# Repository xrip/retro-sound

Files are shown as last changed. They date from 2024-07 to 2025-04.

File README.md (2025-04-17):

# RP2040 Retro Sound

## What is?
RP2040 Retro Sound is a project that enables the Raspberry Pi Pico (RP2040) to serve as a COM port passthrough for various FM retro sound chips like the SAA1099, SN76489, YM3812, and YMF262. 

[Interactive BOM (bill of materials)](https://xrip.github.io/retro-sound/hardware/bom/ibom.html)

Assembled PCB:

assembled pcb

Gerbers available via releases, or you can use whole KiCad project from ``hardware`` folder

With this setup, you can bring the authentic sound of classic gaming and computing systems to life using original sound chips. Enjoy the nostalgia of retro audio in a modern, convenient package!

## Purpose
The goal of this project is to allow enthusiasts to listen to retro sound with real sound chips without needing any other retro hardware.

## How to use
To use this project, you will need a modified version of <a href="https://github.com/xrip/retro-sound-dosbox-x/tree/master">DosBox-X</a> or a Sega Master System/Sega Genesis emulator that can passthrough sound data directly to the chips via a COM port. COM7 hardcoded right now.

The operation protocol is straightforward and consists of two-byte transfers. The first byte is the command byte:

```
/*
 * 76543210 - command byte
 * ||||||||
 * |||||||+-- chip 0 / chip 1
 * ||||||+--- address or data
 * ||||++---- reserved
 * ++++------ 0x0...0xE chip id:
 *
 *            0x0 - SN76489 (Tandy 3 voice)
 *            0x1 - YM2413 (OPLL)
 *            0x2 - YM3812 (OPL2)
 *            0x3 - SAA1099 (Creative Music System / GameBlaster)
 *            0x4 - YMF262 (OPL3)
 *            0x5 - YM2612, YM2203, YM2608, YM2610, YMF288 (OPN2 and OPN-compatible series)
 *            ...
 *            0xf - all chips reset/initialization
 */
```

The second byte is the data byte, which is routed directly to the chip.

## Requirements
1. PCB (gerbers available via releases, or you can use whole KiCad project from ``hardware`` dir)
2. RP2040 mini: The microcontroller that powers the project.
4. Retro Sound Chips: Choose from SN76489, SAA1099, YM2413, YM3812, YMF262, or any OPN2 compatible chip. The YMF262 is recommended for its versatility. 
5. Capacitors and Resistors: A few passive components for stable operation.
6. Basic Soldering Skills: Minimal soldering is required to assemble the hardware.

## Credits
PCB designs and all hardware stuff are by Sa Gin

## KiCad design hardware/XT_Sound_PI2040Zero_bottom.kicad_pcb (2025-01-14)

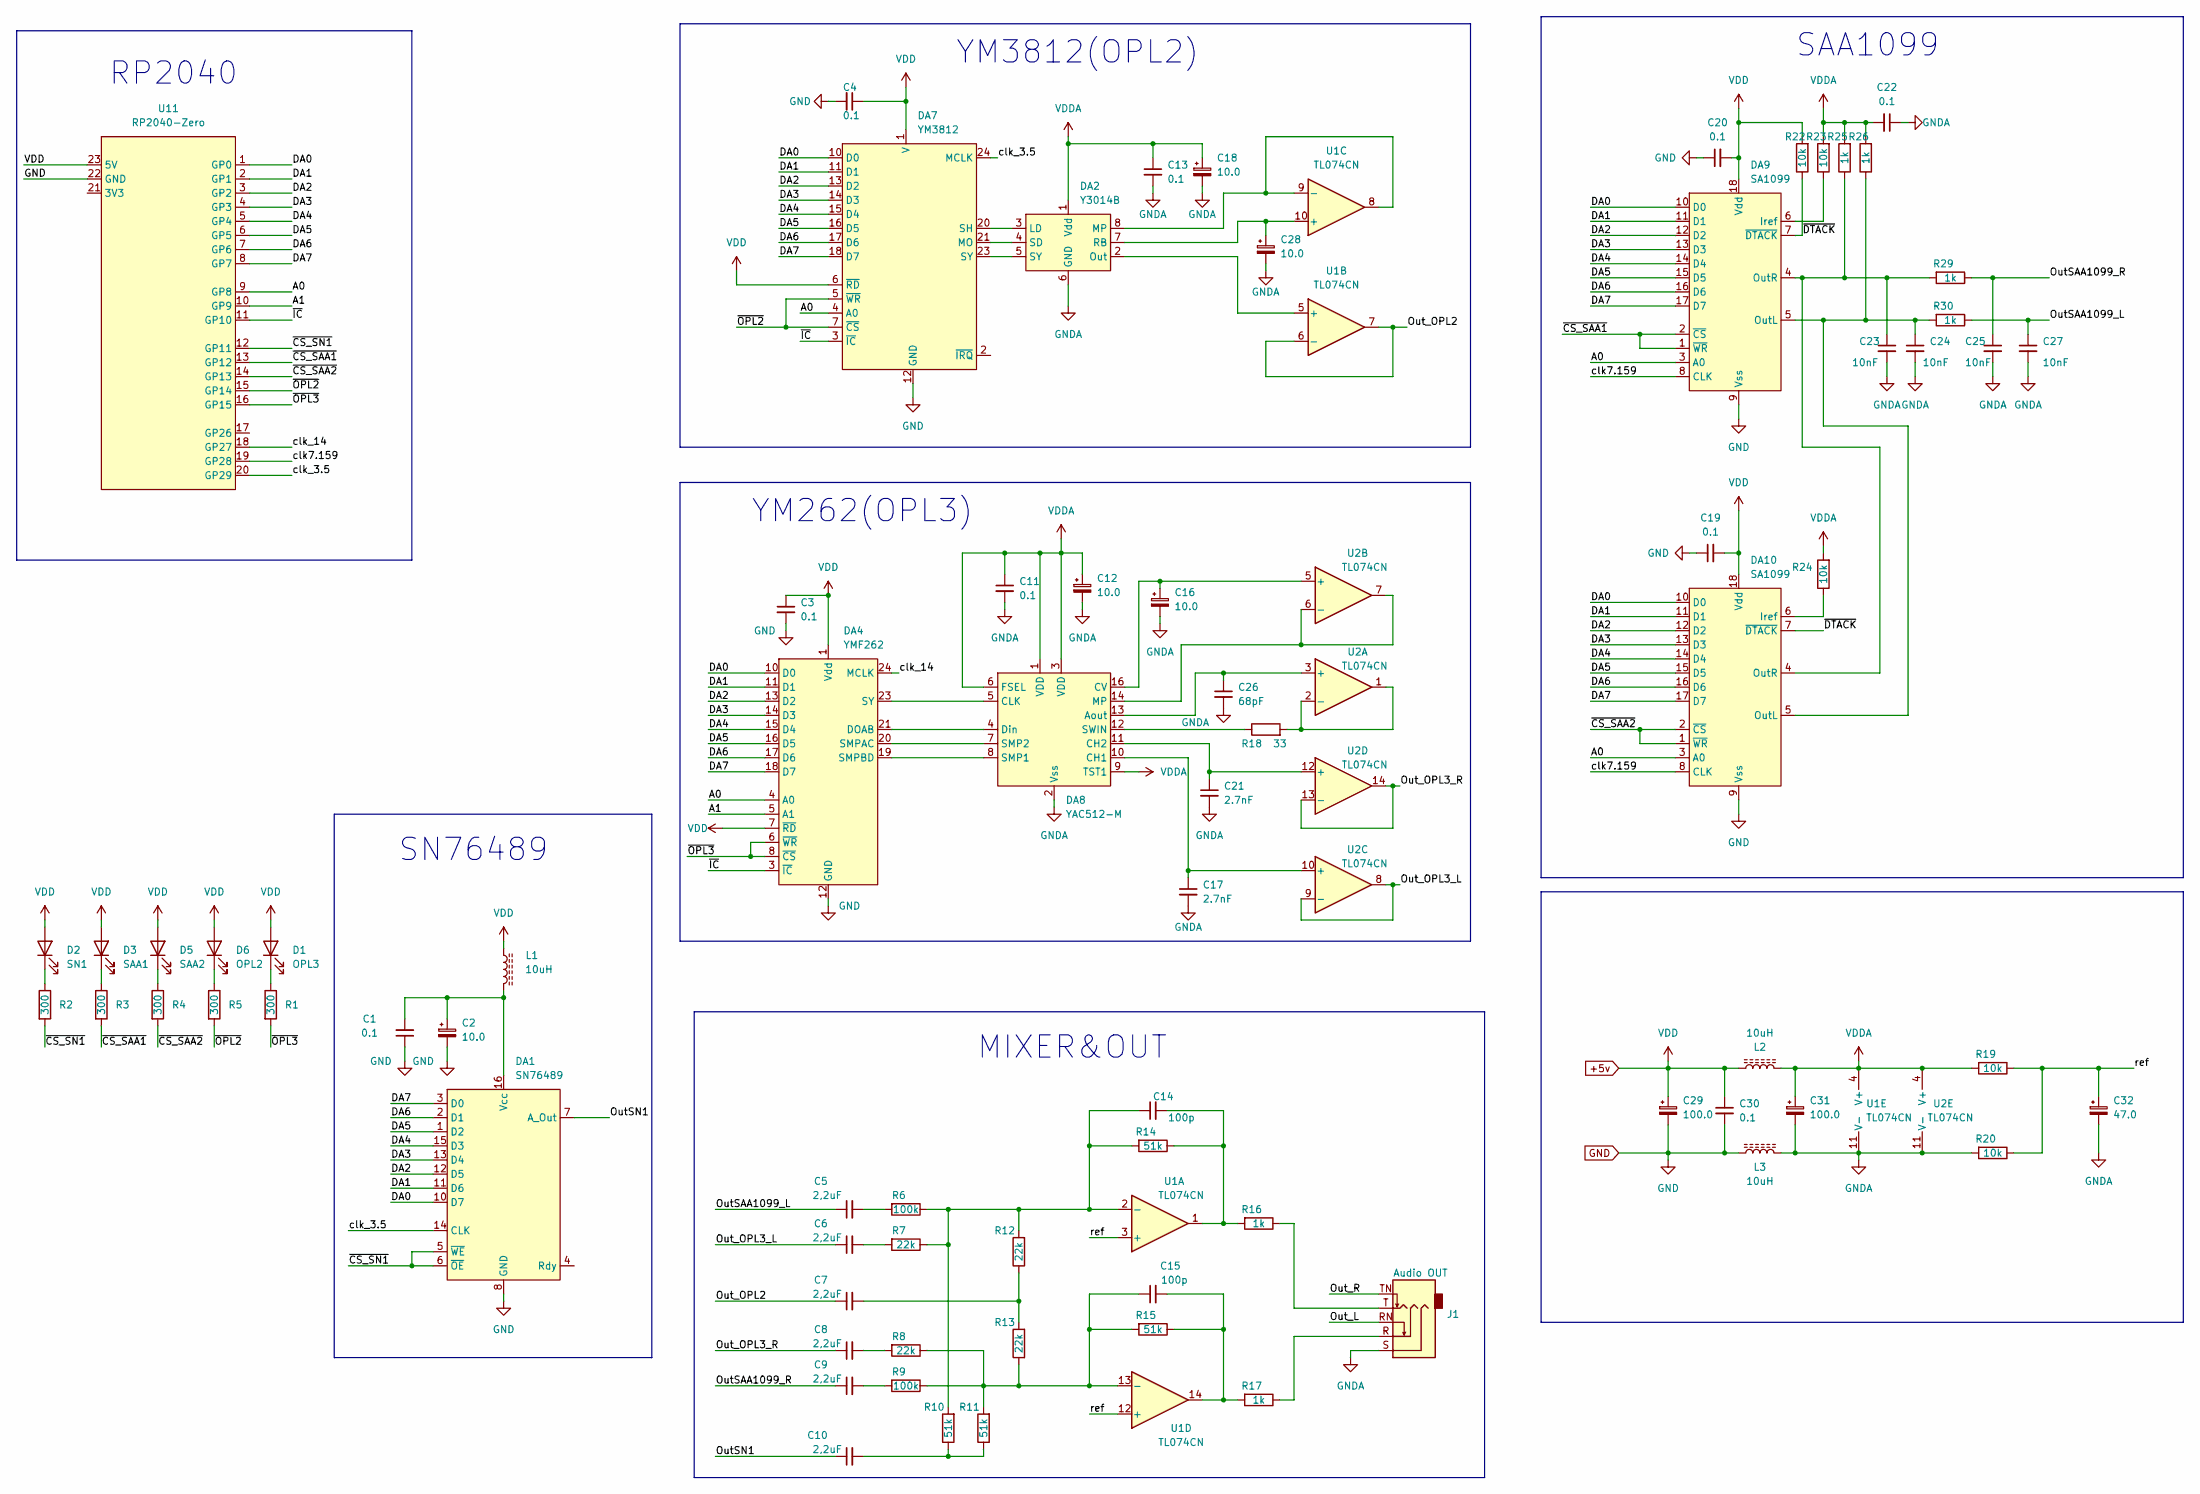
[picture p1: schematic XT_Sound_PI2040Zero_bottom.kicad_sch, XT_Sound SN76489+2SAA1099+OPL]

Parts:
C1, C3, C4, C11, C13, C19, C20, C22, C30: 0.1; C_0805_2012Metric_Pad1.18x1.45mm_HandSolder
C2, C12, C16, C18, C28: 10.0; CP_Elec_4x5.4
C5, C6, C7, C8, C9, C10: 2,2uF; C_0805_2012Metric_Pad1.18x1.45mm_HandSolder
C14, C15: 100p; C_0805_2012Metric_Pad1.18x1.45mm_HandSolder
C17, C21: 2.7nF; C_0805_2012Metric_Pad1.18x1.45mm_HandSolder
C23, C24, C25, C27: 10nF; C_0805_2012Metric_Pad1.18x1.45mm_HandSolder
C26: 68pF; C_0805_2012Metric_Pad1.18x1.45mm_HandSolder
C29, C31: 100.0; CP_Elec_5x5.4
C32: 47.0; CP_Elec_5x5.4
D1: OPL3; LED_Rectangular_W5.0mm_H2.0mm
D2: SN1; LED_Rectangular_W5.0mm_H2.0mm
D3: SAA1; LED_Rectangular_W5.0mm_H2.0mm
D5: SAA2; LED_Rectangular_W5.0mm_H2.0mm
D6: OPL2; LED_Rectangular_W5.0mm_H2.0mm
DA1: SN76489; DIP-16_W7.62mm
DA2: Y3014B; DIP-8_W7.62mm_LongPads
DA4: YMF262; SOP-24_7.5x15.4mm_P1.27mm
DA7: YM3812; DIP-24_W15.24mm
DA8: YAC512-M; SOIC-16_4.55x10.3mm_P1.27mm
DA9, DA10: SA1099; DIP-18_W7.62mm
J1: Audio OUT; Jack_3.5mm_CUI_SJ1-3525N_Horizontal
L1, L2, L3: 10uH; L_0805_2012Metric_Pad1.15x1.40mm_HandSolder
R1, R2, R3, R4, R5: 300; R_0805_2012Metric_Pad1.20x1.40mm_HandSolder
R6, R9: 100k; R_0805_2012Metric_Pad1.20x1.40mm_HandSolder
R7, R8, R12, R13: 22k; R_0805_2012Metric_Pad1.20x1.40mm_HandSolder
R10, R11, R14, R15: 51k; R_0805_2012Metric_Pad1.20x1.40mm_HandSolder
R16, R17, R25, R26, R29, R30: 1k; R_0805_2012Metric_Pad1.20x1.40mm_HandSolder
R18: 33; R_0805_2012Metric_Pad1.20x1.40mm_HandSolder
R19, R20, R22, R23, R24: 10k; R_0805_2012Metric_Pad1.20x1.40mm_HandSolder
U1, U2: TL074CN; DIP-14_W7.62mm_Socket
U11: RP2040-Zero

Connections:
+5v: C3.1, C4.1, C19.2, C20.2, C29.1, C30.1, D1.2 (A), D2.2 (A), D3.2 (A), D5.2 (A), D6.2 (A), DA4.1 (Vdd), DA4.7 (~RD), DA7.1 (V), DA7.6 (~RD), DA9.18 (Vdd), DA10.18 (Vdd), L1.1, L2.1, R22.2, U11.23 (5V)
/A0: DA4.4 (A0), DA7.4 (A0), DA9.3 (A0), DA10.3 (A0), U11.9 (GP8)
/A1: DA4.5 (A1), U11.10 (GP9)
/DA0: DA1.10 (D7), DA4.10 (D0), DA7.10 (D0), DA9.10 (D0), DA10.10 (D0), U11.1 (GP0)
/DA1: DA1.11 (D6), DA4.11 (D1), DA7.11 (D1), DA9.11 (D1), DA10.11 (D1), U11.2 (GP1)
/DA2: DA1.12 (D5), DA4.13 (D2), DA7.13 (D2), DA9.12 (D2), DA10.12 (D2), U11.3 (GP2)
/DA3: DA1.13 (D4), DA4.14 (D3), DA7.14 (D3), DA9.13 (D3), DA10.13 (D3), U11.4 (GP3)
/DA4: DA1.15 (D3), DA4.15 (D4), DA7.15 (D4), DA9.14 (D4), DA10.14 (D4), U11.5 (GP4)
/DA5: DA1.1 (D2), DA4.16 (D5), DA7.16 (D5), DA9.15 (D5), DA10.15 (D5), U11.6 (GP5)
/DA6: DA1.2 (D1), DA4.17 (D6), DA7.17 (D6), DA9.16 (D6), DA10.16 (D6), U11.7 (GP6)
/DA7: DA1.3 (D0), DA4.18 (D7), DA7.18 (D7), DA9.17 (D7), DA10.17 (D7), U11.8 (GP7)
/OutSAA1099_L: C5.1, C27.1, R30.1
/OutSAA1099_R: C9.1, C25.1, R29.1
/OutSN1: C10.1, DA1.7 (A_Out)
/Out_L: J1.RN
/Out_OPL2: C7.1, U1.6 (-), U1.7
/Out_OPL3_L: C6.1, U2.8, U2.9 (-)
/Out_OPL3_R: C8.1, U2.13 (-), U2.14
/Out_R: J1.TN
/clk7.159: DA9.8 (CLK), DA10.8 (CLK), U11.19 (GP28)
/clk_3.5: DA1.14 (CLK), DA7.24 (MCLK), U11.20 (GP29)
/clk_14: DA4.24 (MCLK), U11.18 (GP27)
/ref: C32.1, R19.1, R20.1, U1.3 (+), U1.12 (+)
/~CS_SAA1: DA9.1 (~WR), DA9.2 (~CS), R3.2, U11.13 (GP12)
/~CS_SAA2: DA10.1 (~WR), DA10.2 (~CS), R4.2, U11.14 (GP13)
/~CS_SN1: DA1.5 (~WE), DA1.6 (~OE), R2.2, U11.12 (GP11)
/~DTACK: DA9.7 (~DTACK), DA10.7 (~DTACK), R22.1
/~IC: DA4.3 (~IC), DA7.3 (~IC), U11.11 (GP10)
/~OPL2: DA7.5 (~WR), DA7.7 (~CS), R5.2, U11.15 (GP14)
/~OPL3: DA4.6 (~WR), DA4.8 (~CS), R1.2, U11.16 (GP15)
GND: C1.1, C2.2, C3.2, C4.2, C19.1, C20.1, C29.2, C30.2, DA1.8 (GND), DA4.12 (GND), DA7.12 (GND), DA9.9 (Vss), DA10.9 (Vss), L3.1, U11.22 (GND)
GNDA: C11.2, C12.2, C13.2, C16.2, C17.2, C18.2, C21.2, C22.1, C23.2, C24.2, C25.2, C26.2, C27.2, C28.2, C31.2, C32.2, DA2.6 (GND), DA8.2 (Vss), J1.S, L3.2, R20.2, U1.11 (V-), U2.11 (V-)
unnamed: C1.2, C2.1, DA1.16 (Vcc), L1.2
unnamed: C5.2, R6.2
unnamed: C6.2, R7.2
unnamed: C7.2, R12.1, R13.2
unnamed: C8.2, R8.2
unnamed: C9.2, R9.2
unnamed: C10.2, R10.1, R11.1
unnamed: C14.1, R6.1, R7.1, R10.2, R12.2, R14.2, U1.2 (-)
unnamed: C14.2, R14.1, R16.2, U1.1
unnamed: C15.1, R8.1, R9.1, R11.2, R13.1, R15.2, U1.13 (-)
unnamed: C15.2, R15.1, R17.2, U1.14
unnamed: C16.1, DA8.16 (CV), U2.5 (+)
unnamed: C17.1, DA8.10 (CH1), U2.10 (+)
unnamed: C21.1, DA8.11 (CH2), U2.12 (+)
unnamed: C23.1, DA9.4 (OutR), DA10.4 (OutR), R25.1, R29.2
unnamed: C24.1, DA9.5 (OutL), DA10.5 (OutL), R26.1, R30.2
unnamed: C26.1, DA8.13 (Aout), U2.3 (+)
unnamed: C28.1, DA2.7 (RB), U1.10 (+)
unnamed: D1.1 (K), R1.1
unnamed: D2.1 (K), R2.1
unnamed: D3.1 (K), R3.1
unnamed: D5.1 (K), R4.1
unnamed: D6.1 (K), R5.1
unnamed: DA2.2 (Out), U1.5 (+)
unnamed: DA2.3 (LD), DA7.20 (SH)
unnamed: DA2.4 (SD), DA7.21 (MO)
unnamed: DA2.5 (SY), DA7.23 (SY)
unnamed: DA2.8 (MP), U1.8, U1.9 (-)
unnamed: DA4.19 (SMPBD), DA8.8 (SMP1)
unnamed: DA4.20 (SMPAC), DA8.7 (SMP2)
unnamed: DA4.21 (DOAB), DA8.4 (Din)
unnamed: DA4.23 (SY), DA8.5 (CLK)
unnamed: DA8.12 (SWIN), R18.1
unnamed: DA8.14 (MP), U2.6 (-), U2.7
unnamed: DA9.6 (Iref), R23.1
unnamed: DA10.6 (Iref), R24.1
unnamed: J1.R, R17.1
unnamed: J1.T, R16.1
unnamed: R18.2, U2.1, U2.2 (-)
VDDA: C11.1, C12.1, C13.1, C18.1, C22.2, C31.1, DA2.1 (Vdd), DA8.1 (VDD), DA8.3 (VDD), DA8.6 (FSEL), DA8.9 (TST1), L2.2, R19.2, R23.2, R24.2, R25.2, R26.2, U1.4 (V+), U2.4 (V+)

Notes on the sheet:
YM262(OPL3)
YM3812(OPL2)
MIXER&OUT
SAA1099
RP2040
SN76489

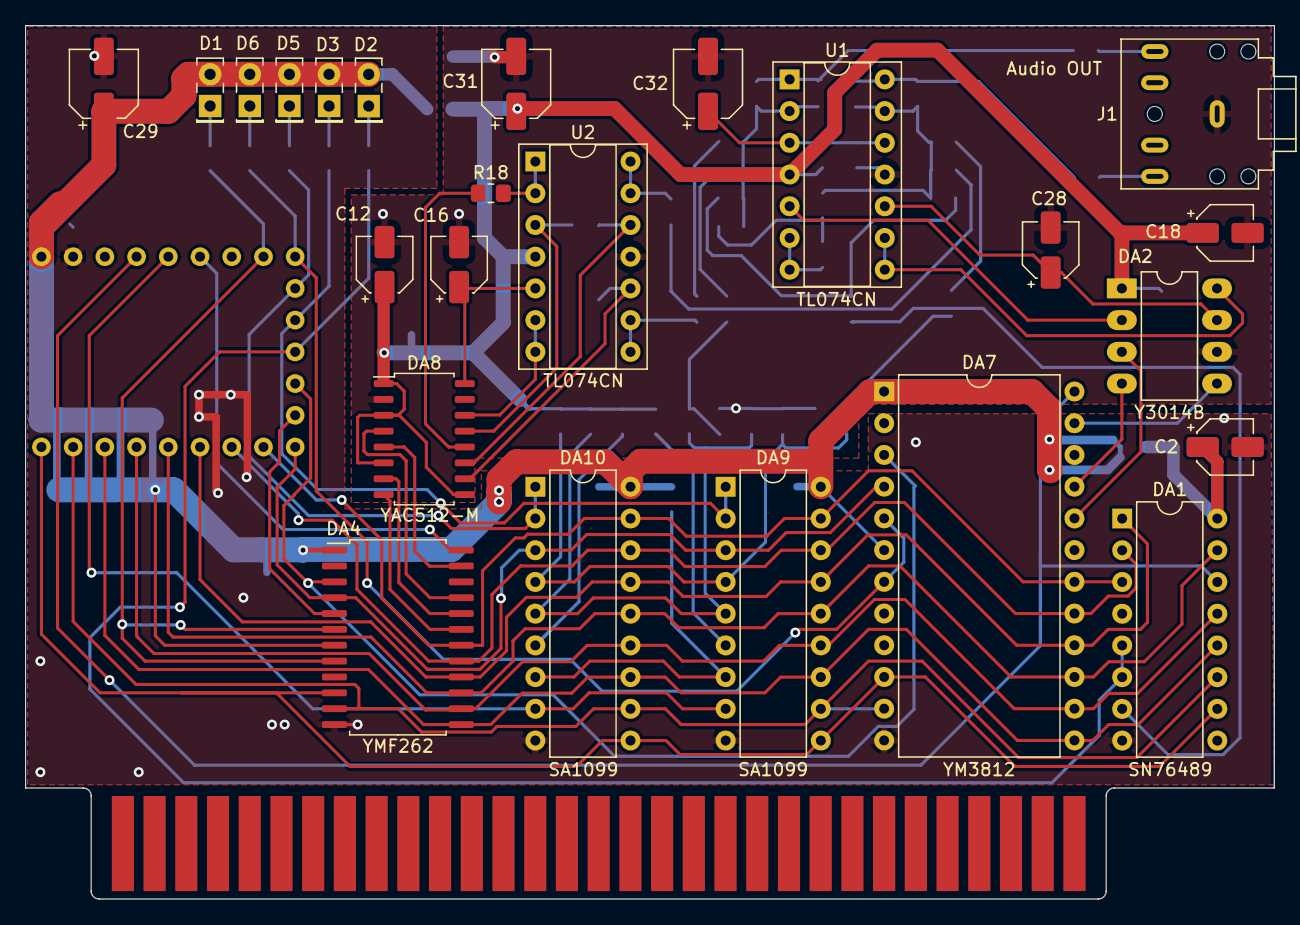
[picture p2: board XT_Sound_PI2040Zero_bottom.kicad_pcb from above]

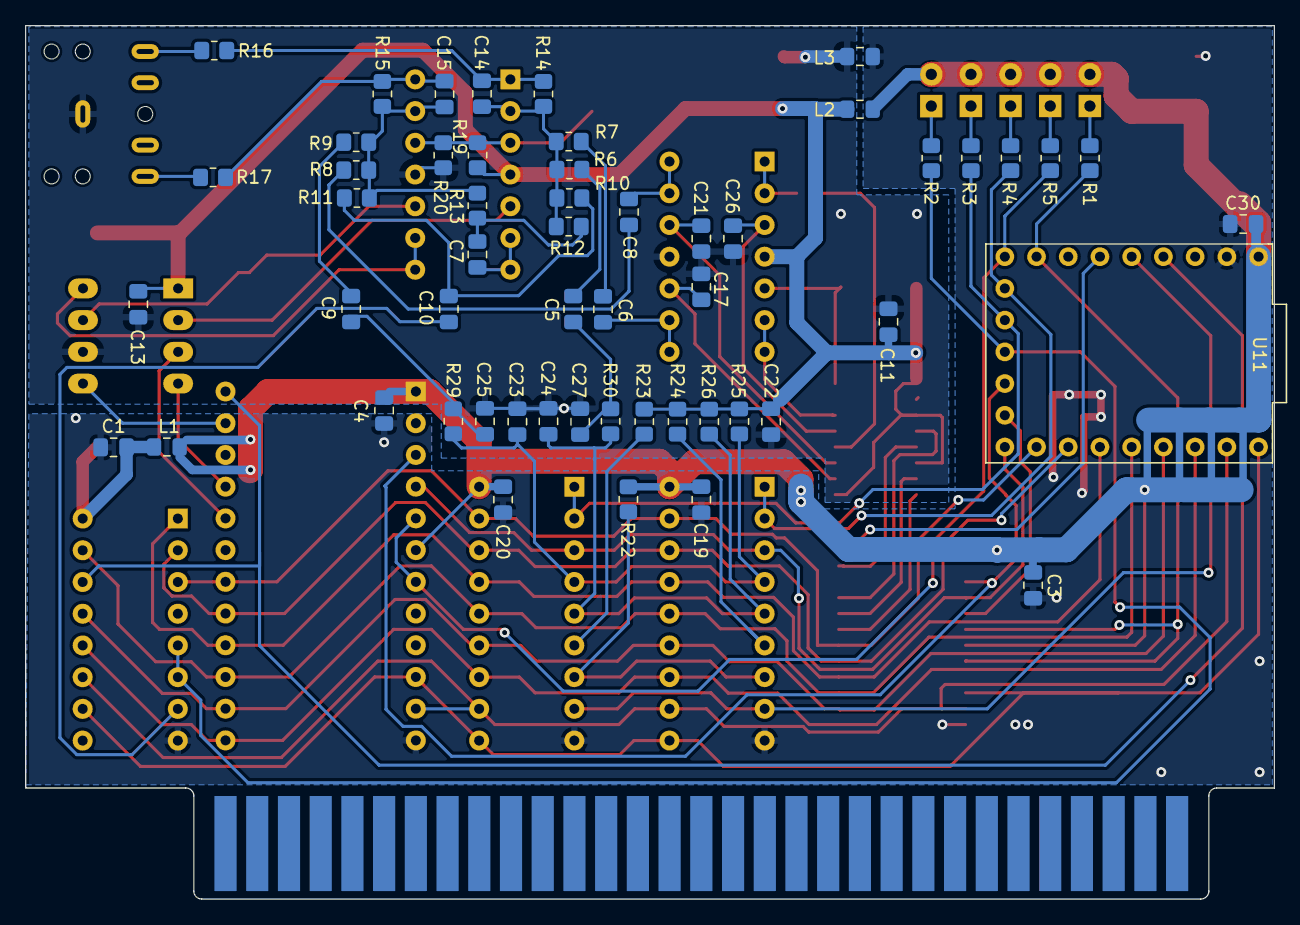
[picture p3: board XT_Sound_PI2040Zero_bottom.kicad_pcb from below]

Board: 2 copper layers, 100.0 x 69.9 mm, 78 parts (54 on the bottom side), 70 nets.

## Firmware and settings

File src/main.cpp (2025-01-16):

#include <cstdio>
#include <pico/stdio_usb.h>
#include <pico/runtime.h>
#include <pico/multicore.h>
#include <hardware/structs/vreg_and_chip_reset.h>
#include <hardware/structs/clocks.h>
#include <hardware/clocks.h>
#include <hardware/gpio.h>

#include "ws2812b.h"
#include "pio_clock_generator.h"

#define TIMER_PERIOD_MS 1

#define OUT_PIN_MASK 0x0000ffff
#define IC (1 << 8)
#define A0 (1 << 9)
#define A1 (1 << 10)

#define SN_1_CS  (1 << 11)
#define SAA_1_CS (1 << 12)
#define SAA_2_CS (1 << 13)
#define OPL2     (1 << 14)
#define OPL3     (1 << 15)


uint16_t control_bits = 0;
#define LOW(x) (control_bits &= ~(x))
#define HIGH(x) (control_bits |= (x))


#if defined(SN76489_REVERSED)
// Если мы перепутаем пины
static const uint8_t  __aligned(4) reversed[] = {
        0x00, 0x80, 0x40, 0xC0, 0x20, 0xA0, 0x60, 0xE0, 0x10, 0x90, 0x50, 0xD0, 0x30, 0xB0, 0x70, 0xF0,
        0x08, 0x88, 0x48, 0xC8, 0x28, 0xA8, 0x68, 0xE8, 0x18, 0x98, 0x58, 0xD8, 0x38, 0xB8, 0x78, 0xF8,
        0x04, 0x84, 0x44, 0xC4, 0x24, 0xA4, 0x64, 0xE4, 0x14, 0x94, 0x54, 0xD4, 0x34, 0xB4, 0x74, 0xF4,
        0x0C, 0x8C, 0x4C, 0xCC, 0x2C, 0xAC, 0x6C, 0xEC, 0x1C, 0x9C, 0x5C, 0xDC, 0x3C, 0xBC, 0x7C, 0xFC,
        0x02, 0x82, 0x42, 0xC2, 0x22, 0xA2, 0x62, 0xE2, 0x12, 0x92, 0x52, 0xD2, 0x32, 0xB2, 0x72, 0xF2,
        0x0A, 0x8A, 0x4A, 0xCA, 0x2A, 0xAA, 0x6A, 0xEA, 0x1A, 0x9A, 0x5A, 0xDA, 0x3A, 0xBA, 0x7A, 0xFA,
        0x06, 0x86, 0x46, 0xC6, 0x26, 0xA6, 0x66, 0xE6, 0x16, 0x96, 0x56, 0xD6, 0x36, 0xB6, 0x76, 0xF6,
        0x0E, 0x8E, 0x4E, 0xCE, 0x2E, 0xAE, 0x6E, 0xEE, 0x1E, 0x9E, 0x5E, 0xDE, 0x3E, 0xBE, 0x7E, 0xFE,
        0x01, 0x81, 0x41, 0xC1, 0x21, 0xA1, 0x61, 0xE1, 0x11, 0x91, 0x51, 0xD1, 0x31, 0xB1, 0x71, 0xF1,
        0x09, 0x89, 0x49, 0xC9, 0x29, 0xA9, 0x69, 0xE9, 0x19, 0x99, 0x59, 0xD9, 0x39, 0xB9, 0x79, 0xF9,
        0x05, 0x85, 0x45, 0xC5, 0x25, 0xA5, 0x65, 0xE5, 0x15, 0x95, 0x55, 0xD5, 0x35, 0xB5, 0x75, 0xF5,
        0x0D, 0x8D, 0x4D, 0xCD, 0x2D, 0xAD, 0x6D, 0xED, 0x1D, 0x9D, 0x5D, 0xDD, 0x3D, 0xBD, 0x7D, 0xFD,
        0x03, 0x83, 0x43, 0xC3, 0x23, 0xA3, 0x63, 0xE3, 0x13, 0x93, 0x53, 0xD3, 0x33, 0xB3, 0x73, 0xF3,
        0x0B, 0x8B, 0x4B, 0xCB, 0x2B, 0xAB, 0x6B, 0xEB, 0x1B, 0x9B, 0x5B, 0xDB, 0x3B, 0xBB, 0x7B, 0xFB,
        0x07, 0x87, 0x47, 0xC7, 0x27, 0xA7, 0x67, 0xE7, 0x17, 0x97, 0x57, 0xD7, 0x37, 0xB7, 0x77, 0xF7,
        0x0F, 0x8F, 0x4F, 0xCF, 0x2F, 0xAF, 0x6F, 0xEF, 0x1F, 0x9F, 0x5F, 0xDF, 0x3F, 0xBF, 0x7F, 0xFF
};
#endif

static inline bool overclock() {
    hw_set_bits(&vreg_and_chip_reset_hw->vreg, VREG_AND_CHIP_RESET_VREG_VSEL_BITS);
    sleep_ms(10);
    return set_sys_clock_khz(396 * KHZ, true);
}

static inline void write_GPIO(const uint16_t data, const uint16_t delay_us) {
    gpio_put_masked(OUT_PIN_MASK, data);
    busy_wait_us(delay_us);
}


static inline uint32_t time_ms() {
    return time_us_32() >> 10; //0-4194190
}


// SN76489
static inline void SN76489_write(uint8_t byte) {
#if defined(SN76489_REVERSED)
    byte = reversed[byte];
#endif
    write_GPIO(byte | LOW(SN_1_CS), 20);
    write_GPIO(byte | HIGH(SN_1_CS), 0);
}

// YM2413
static inline void YM2413_write(const uint8_t addr, const uint8_t byte) {
    const uint16_t a0 = addr ? A0 : 0;
    write_GPIO(byte | a0 | LOW(OPL2), 4);
    write_GPIO(byte | a0 | HIGH(OPL2), a0 ? 30 : 5);
}

// SAA1099
static inline void SAA1099_write(const uint8_t addr, const uint8_t chip, const uint8_t byte) {
    const uint16_t a0 = addr ? A0 : 0;
    const uint16_t cs = chip ? SAA_2_CS : SAA_1_CS;

    write_GPIO(byte | a0 | LOW(cs), 5);
    write_GPIO(byte | a0 | HIGH(cs), 0);
}

// YM3812
static inline void YM3812_write_byte(const uint16_t addr, const uint16_t register_set, const uint8_t byte) {
    const uint16_t a0 = addr ? A0 : 0;
    const uint16_t a1 = register_set ? A1 : 0;

    write_GPIO(byte | a0 | a1 | LOW(OPL2), 5);
    write_GPIO(byte | a0 | a1 | HIGH(OPL2), 30);
}

// YMF262
static inline void YMF262_write_byte(const uint16_t addr, const uint16_t register_set, const uint8_t byte) {
    const uint16_t a0 = addr ? A0 : 0;
    const uint16_t a1 = register_set ? A1 : 0;

    write_GPIO(byte | a0 | a1 | LOW(OPL3), 5);
    write_GPIO(byte | a0 | a1 | HIGH(OPL3), 0);
}

enum chip_type {
    SN76489,
    YM2413,
    YM3812,
    SAA1099,
    YMF262,
    YM2612,
    PCM,
};

/*
 * 76543210 - command byte
 * ||||||||
 * |||||||+-- chip 0 / chip 1
 * ||||||+--- address or data
 * ||||++---- reserved
 * ++++------ 0x0...0xE chip id:
 *
 *            0x0 - SN76489 (Tandy 3 voice)
 *            0x1 - YM2413 (OPLL)
 *            0x2 - YM3812 (OPL2)
 *            0x3 - SAA1099 (Creative Music System / GameBlaster)
 *            0x4 - YMF262 (OPL3)
 *            0x5 - YM2612, YM2203, YM2608, YM2610, YMF288 (OPN2 and OPN-compatible series)
 *            ...
 *            0xf - all chips reset/initialization
 */

#define CHIP(b) (b >> 4)
#define CHIPN(b) (b & 1)
#define TYPE(b) (b & 2)

static inline void reset_chips() {
    control_bits = 0;
    write_GPIO(HIGH(SN_1_CS | OPL2 | SAA_1_CS | SAA_2_CS | OPL3 | IC), 10);
    write_GPIO(LOW(IC), 100);
    write_GPIO(HIGH(IC), 10);

    // Mute SN76489
    SN76489_write(0x9F);
    SN76489_write(0xBF);
    SN76489_write(0xDF);
    SN76489_write(0xFF);

    // Mute SAA1099
    SAA1099_write(1, 0, 0x1C);
    SAA1099_write(0, 0, 0);
    SAA1099_write(1, 1, 0x1C);
    SAA1099_write(0, 1, 0);

    for (int i = 0; i < 6; i++) {
        set_ws2812b_HSV(0, i * 40, 250, 40);
        sleep_ms(60);
    }
}

int __time_critical_func() main() {
    overclock();

    stdio_usb_init();

    gpio_init_mask(OUT_PIN_MASK);
    gpio_set_dir_out_masked(OUT_PIN_MASK);

    ini_chips_clocks();

    init_ws2812b();

    reset_chips();

    uint8_t ws2812b_color = 0;
    uint8_t ws2812b_brightness = 0;
    uint32_t timer_update = 0;

    int is_data_byte = false;
    uint8_t command = 0;

    while (true) {
        const int data = getchar_timeout_us(50);

        if (time_ms() - timer_update > TIMER_PERIOD_MS) {
            timer_update = time_ms();

            set_ws2812b_HSV(0, ws2812b_color, 250, ws2812b_brightness);

            if (ws2812b_brightness)
                ws2812b_brightness--;
        }


        if (PICO_ERROR_TIMEOUT != data) {
            if (is_data_byte) {
                ws2812b_brightness = 60;

                switch (CHIP(command)) {
                    case SN76489: /* TODO: GameGear channel mapping */
                        SN76489_write(data);
                        ws2812b_color = 0;
                        break;

                    case YM2413:
                        YM2413_write(TYPE(command), data);
                        ws2812b_color = 30;
                        break;

                    case YMF262:
                        YMF262_write_byte(TYPE(command), CHIPN(command), data);
                        ws2812b_color = 30;
                        break;

                    case YM3812:
                        YM3812_write_byte(TYPE(command), CHIPN(command), data);
                        ws2812b_color = 60;
                        break;

                    case SAA1099:
                        SAA1099_write(TYPE(command), CHIPN(command), data);
                        ws2812b_color = 120;
                        break;

                    case 0xf:
                        reset_chips();
                        break;
                }
            }

            command = data;
            is_data_byte ^= 1;
        }
    }
}

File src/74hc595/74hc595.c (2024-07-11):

#include "74hc595.h"
#include "hardware/clocks.h"
#include "pico/platform.h"

static const uint16_t program_instructions595[] = {
        //     .wrap_target
        0x80a0, //  0: pull   block           side 0
        0x6001, //  1: out    pins, 1         side 0
        0x1041, //  2: jmp    x--, 1          side 2
        0xe82f, //  3: set    x, 15           side 1
        0x6050, //  4: out    y, 16           side 0
        0x0085, //  5: jmp    y--, 5          side 0
        //     .wrap

};

static const struct pio_program program595 = {
        .instructions = program_instructions595,
        .length = 6,
        .origin = -1,
};

void init_74hc595() {
    uint offset = pio_add_program(PIO_74HC595, &program595);
    pio_sm_config c = pio_get_default_sm_config();
    sm_config_set_wrap(&c, offset, offset + (program595.length - 1));
    sm_config_set_fifo_join(&c, PIO_FIFO_JOIN_TX);

    // sm_config_set_in_shift(&c, true, false, 32);//??????  
    // sm_config_set_in_pins(&c, PIN_PS2_DATA);

//     pio_gpio_init(pioAY595, CLK_LATCH_595_BASE_PIN);
//     pio_gpio_init(pioAY595, CLK_LATCH_595_BASE_PIN+1);
// //pio_sm_set_consecutive_pindirs(pio, sm, pin, 1, true);
//     sm_config_set_sideset_pins(&c, CLK_LATCH_595_BASE_PIN);

//     sm_config_set_set_pins(&c, CLK_LATCH_595_BASE_PIN, 2);
//     sm_config_set_sideset(&c, 2, false, false);


    //настройка side set
    sm_config_set_sideset_pins(&c, CLK_LATCH_595_BASE_PIN);
    sm_config_set_sideset(&c, 2, false, false);

    for (int i = 0; i < 2; i++) {
        pio_gpio_init(PIO_74HC595, CLK_LATCH_595_BASE_PIN + i);
    }

    pio_sm_set_pins_with_mask(PIO_74HC595, SM_74HC595, 3u << CLK_LATCH_595_BASE_PIN, 3u << CLK_LATCH_595_BASE_PIN);
    pio_sm_set_pindirs_with_mask(PIO_74HC595, SM_74HC595, 3u << CLK_LATCH_595_BASE_PIN, 3u << CLK_LATCH_595_BASE_PIN);
    //

    pio_gpio_init(PIO_74HC595, DATA_595_PIN);//резервируем под выход PIO

    pio_sm_set_consecutive_pindirs(PIO_74HC595, SM_74HC595, DATA_595_PIN, 1, true);//конфигурация пинов на выход

    sm_config_set_out_shift(&c, false, false, 32);
    sm_config_set_out_pins(&c, DATA_595_PIN, 1);

    pio_sm_init(PIO_74HC595, SM_74HC595, offset, &c);
    pio_sm_set_enabled(PIO_74HC595, SM_74HC595, true);

    pio_sm_set_clkdiv(PIO_74HC595, SM_74HC595, clock_get_hz(clk_sys) / SHIFT_SPEED);
    PIO_74HC595->txf[SM_74HC595] = 0;


};

void __not_in_flash_func(write_74hc595)(uint16_t data, uint16_t delay_us) {
    PIO_74HC595->txf[SM_74HC595] = data << 16 | delay_us << 4; // 1 microsecond per 15 cycles @ 15Mhz
}
